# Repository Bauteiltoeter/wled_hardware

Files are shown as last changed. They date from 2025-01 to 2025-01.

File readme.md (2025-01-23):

# Universal WLED board with ethernet switch

This projects aims to deliver a hardware platform to drive smart LEDs like WS2812, SK6812 and similar.
It can operate from the LED strips supply voltage (5-24V) and provides a webinterface over WiFi or Ethernet.
The integrated ethernet switch enables an ethernet daisy chain.
Each LED output is individually fused to allow for thiner wires and high current powersupplies.
Some smart LEDs have trouble reading 3.3V data signals with a high supply voltage. This board contains a 5V output driver to avoide data corruption.

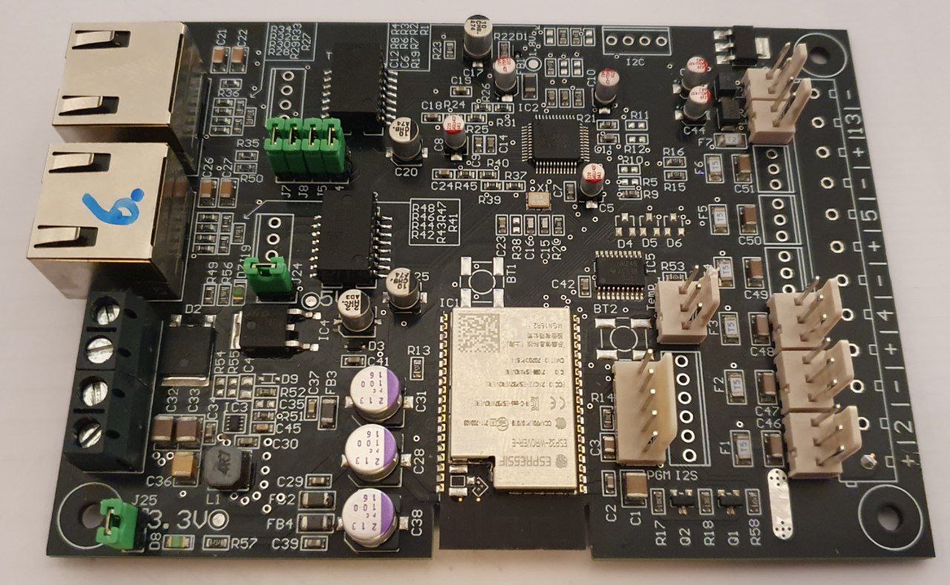
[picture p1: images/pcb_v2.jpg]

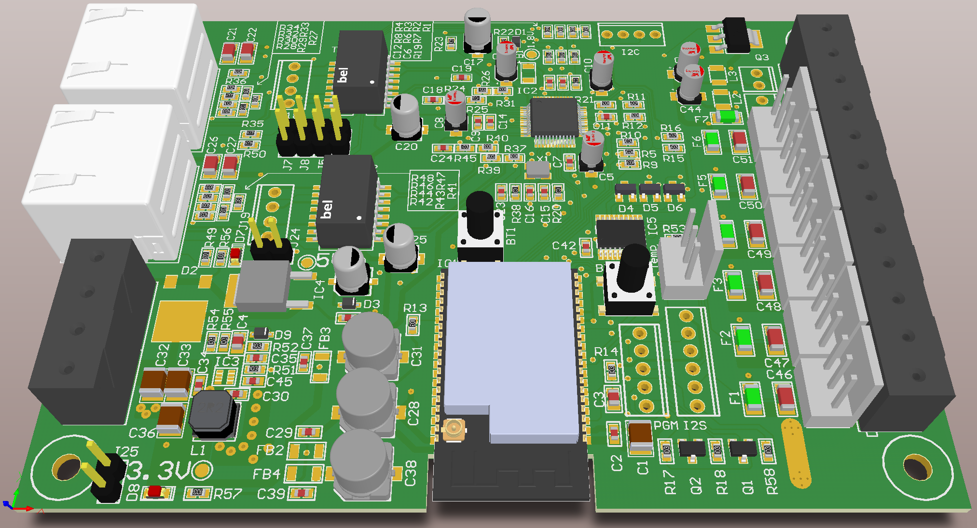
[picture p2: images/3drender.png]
3D Rendering of the board


## Features
* WLED compatible
* Input Voltage 5-24V
* Integrated Ethernet switch for daisy chaining
* 6 LED outputs with 5V signal level
* 5A per output, 16A total
* Every output fused individually
* Output using 2.54mm pins or AKZ500 screw terminals
* 2 fan connectors with PWM
* Connector for DS18B12 temperature sensors
* Connector for I2S microphones (shared with LED output 4/5)
* LEDs can be disabled with jumpers
* Reverse protection diode, will short-circuit the supply if reversed
* Board size 110 x 80mm

## Building it
PCB manufacturing data (gerber), schematic and (mostly) mouser BOM are available in directory "hardware/releases/". PCB was manufactured by JLCPCB including stencil, but hand soldering is an option (L1 needs hot air soldering).
Solder thick wires (1.5 - 2.5mm2) on the exposed traces on the bottom to allow high output currents.

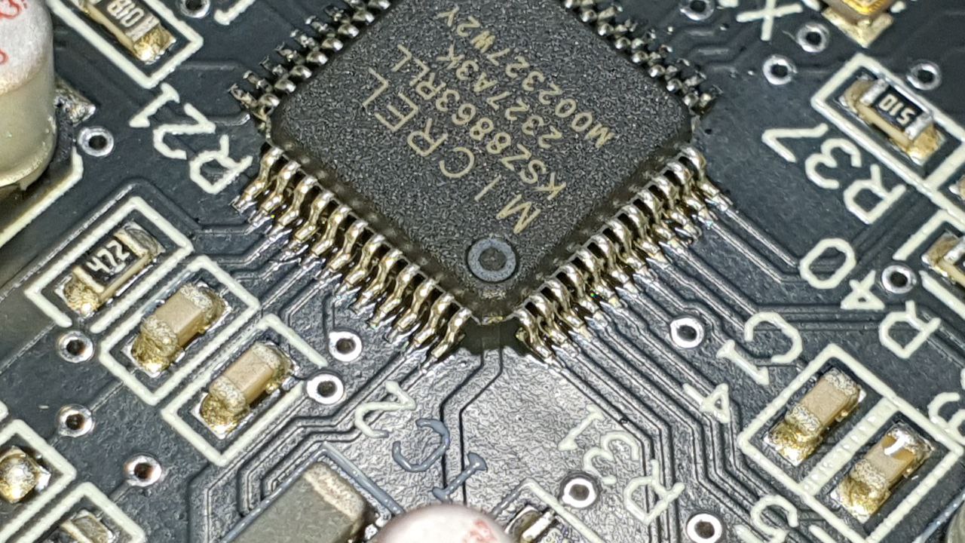
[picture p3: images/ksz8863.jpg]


## Cost
BOM costs are around 45€ + Board + Stencil

## License
This hardware is licensed under CERN open hardware license [CERN-OHL-W](license.txt)

## Software
Compatible with my fork of WLED, available [here](https://github.com/Bauteiltoeter/WLED2/tree/cyberlamp).

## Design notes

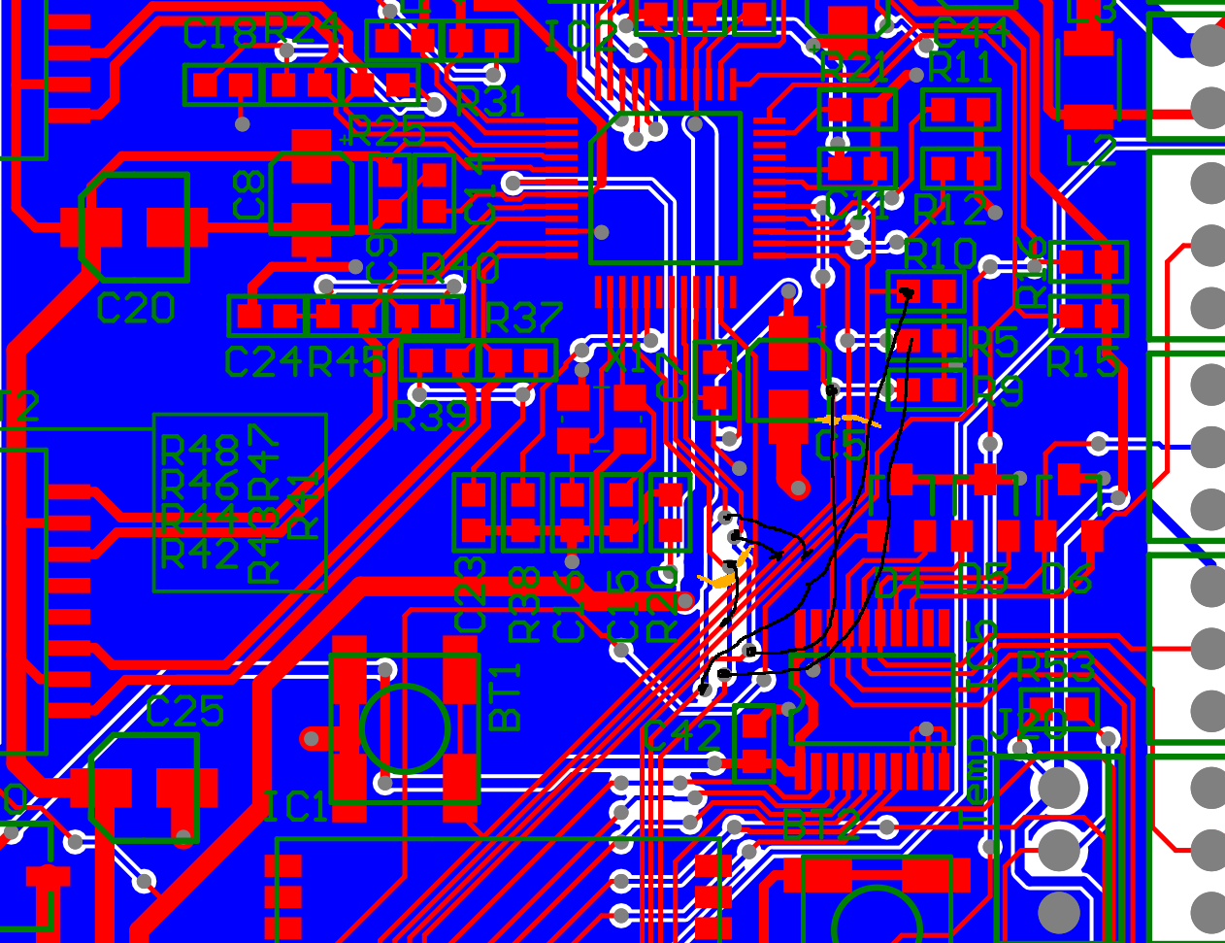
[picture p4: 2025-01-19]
hardware/cyberlamp/mod.png

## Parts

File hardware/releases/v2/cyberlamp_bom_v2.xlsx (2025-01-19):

Comment | Designator | Footprint | mouser code | Quantity | Price/piece | Sum
51R 100mW 0603 | R24, R25, R26, R28, R29, R30, R31, R32, R33, R34, R37, R39, R40, R42, R43, R44, R45, R46, R47, R48 | res0603 | 791-WR06X510JTR | 20 | 0.013 € | 0.260 €
100nF 50V MLCC 0603 | C2, C6, C7, C9, C11, C12, C14, C18, C19, C23, C24, C29, C30, C34, C37, C39, C41, C42 | 0603 | 80-C0603X104K3R | 18 | 0.034 € | 0.612 €
1k 100mW 0603 | R2, R3, R9, R21, R23 | res0603 |  | 5 | 0.034 € | 0.170 €
4k7 100mW 0603 | R8, R13, R15, R16, R19, R53, R56, R58 | res0603 | 603-RE0603FRE074K7L | 8 | 0.080 € | 0.640 €
5A/63V Fuse, 1206 | F1, F2, F3, F4, F5, F6, F7 | 1206 | 530-C1T5 | 7 | 0.211 € | 1.477 €
PSS 254/3G | J12, J13, J14, J15, J16, J17, J20 | PSS 3pol | Reichelt PSS 254/3G | 7 | 0.040 € | 0.280 €
10K 100mW 0603 | R14, R17, R18, R22, R52 | res0603 | 603-RE0603FRE0710KL | 5 | 0.008 € | 0.040 €
1µF 50V MLCC 1206 | C46, C47, C48, C49, C50, C51 | 1206 | 810-C3216X7R1H105K | 6 | 0.063 € | 0.378 €
Elko 22µF 6.3V WE | C5, C8, C10, C13, C43, C44 | WCAP-ASLU | 710-865090168010 | 6 | 0.271 € | 1.626 €
SL 1X2G 2,54 | J4, J5, J7, J8, J24, J25 | SL_1x2 2.54mm |  | 6 |  | 0.000 €
220R 100mW 0603 | R35, R36, R49, R50 | res0603 |  | 4 | 0.008 € | 0.032 €
HI1206N101R-10 | FB1, FB2, FB3, FB4 | 1206 | 875-HI1206N101R-10 | 4 | 0.132 € | 0.528 €
NP0 | C21, C22, C26, C27 | 1206 | 710-885342208024 | 4 | 0.094 € | 0.376 €
CDSOT23-SM712 | D4, D5, D6 | SOT23 | 652-CDSOT23-SM712 | 3 |  | 0.000 €
Elko_100uF_16V_PanasonicC | C28, C31, C38 | PANASONIC_C | 667-16SVPC100M | 3 | 0.499 € | 1.497 €
Elko_10uF_16V_PanasonicB | C17, C20, C25 | Panasonic_b | 667-EEE-HB1C100R | 3 | 0.126 € | 0.378 €
PSS 254/4G | J18, J19, J23 | PSS 4pol | Reichelt PSS 254/4G | 3 | 0.100 € | 0.300 €
18pF 50V MLCC 0603 | C15, C16 | 0603 | 603-CC0603JRNPABN180 | 2 | 0.046 € | 0.092 €
1N4148WS | D1, D3 | SOD323 | 512-1N4148WS | 2 | 0.106 € | 0.212 €
1µF 25V MLCC 0805 | C3 | 0805 | 187-CL21B105KAFNFNE | 1 | 0.028 € | 0.028 €
22uF 35V X5R 1210 | C32, C33 | 1210 | 963-GMK325BJ226MM-P | 2 | 0.476 € | 0.952 €
75R 100mW 0603 | R27, R41 | res0603 | 603-RC0603FR-7W75RL | 2 | 0.020 € | 0.040 €
AKZ500 | J9, J10 | AKZ500/2 | 845-34.102 | 2 | 0.646 € | 1.292 €
FMMT 617 | Q1, Q2 | SOT-23 | 522-FMMT617TA | 2 | 0.245 € | 0.490 €
Green LED, 0603 | D7, D8 | G0805 | 710-150080GS75000 | 2 | 0.174 € | 0.348 €
PSS 254/2G | J21, J22 | PSS 2pol | Reichelt PSS 254/2G | 2 | 0.050 € | 0.100 €
RJ45 | J3, J6 | MTJ-88ARX1-FSM-PG-LH | 737-MTJ88ARX1FSMPGLH | 2 | 0.761 € | 1.522 €
S558-5999-U7-F | T1, T2 | S558-5999-U7-F | 530-S558-5999-U7-F | 2 | 1.430 € | 2.860 €
TDL_NL322522 | L2, L3 | NL322522 | 810-NLV32T-220J-EF | 2 | 0.142 € | 0.284 €
TL3301 JLead | BT1, BT2 | TL3301_Jlead | 612-TL3301TF160QJ | 2 | 0.363 € | 0.726 €
10nF 50V MLCC 0603 | C45 | 0603 |  | 1 |  | 0.000 €
10uF 63V X7R 1210 | C1 | 1210 | 81-GRM32ER71J106MA2L | 1 | 0.537 € | 0.537 €
11k8 100mW 0603 | R20 | res0603 | 603-RT0603DRE0711K8L | 1 | 0.031 € | 0.031 €
2,2µF 50V Size B Elko | C40 | SIZE_B | 667-EEE-HC1H2R2R | 1 | 0.163 € | 0.163 €
25MHz | X1 | ABM8 | 815-ABM8-25-B2-T | 1 | 0.474 € | 0.474 €
2k7 100mW 0603 | R57 | res0603 | 603-RE0603FRE072K7L | 1 | 0.011 € | 0.011 €
30k9 100mW 0603 | R51 | res0603 | 652-CR0603-FX3092ELF | 1 | 0.012 € | 0.012 €
47pF MLCC 0603 | C35 | 0603 | 187-CL10C470JC81PNC | 1 | 0.014 € | 0.014 €
47uF 16V X7R 1210 | C36 | 1210 | GRM32ER61C476KE15L | 1 | 0.698 € | 0.698 €
74AHCT245 | IC5 | TSSOP20 | 595-SN74AHCT245PWRE4 | 1 | 0.626 € | 0.626 €
AKZ500 | J11 | AKZ500/12 | 845-34.112 | 1 | 2.130 € | 2.130 €
BUK98180 | Q3 | SOT223 | 771-BUK98180-100ACUX | 1 | 0.419 € | 0.419 €
BZT52-C4V3S_R1_00001 | D9 | SOD323 | 241-BZT52C4V3SR10000 | 1 | 0.075 € | 0.075 €
ESP32-WROVER-E | IC1 | ESP32-WROVER-I | 356-ESP32WRVREN16R2 | 1 | 3.450 € | 3.450 €
KSZ8863RLL | IC2 | LQFP48 | 998-KSZ8863RLL | 1 | 5.510 € | 5.510 €
L77805CDT-TR | IC4 | D-PAK | 511-L7805CDT-TR | 1 | 0.841 € | 0.841 €
PSS 254/5G | J1 | PSS 5pol | Reichelt PSS 254/5G | 1 | 0.070 € | 0.070 €
PSS 254/6G | J2 | PSS 6pol | Reichelt PSS 254/6G | 1 | 0.160 € | 0.160 €
SRN5040-4R7M | L1 | BOURNS SRN5040 | 652-SRN5040-4R7M | 1 | 0.278 € | 0.278 €
TPS62933F | IC3 | SOT583-8 | 595-TPS62933FDRLR | 1 | 0.939 € | 0.939 €
V20PWM12H | D2 | TO-252AE | 78-V20PWM12HM3/I | 1 | 0.739 € | 0.739 €
DNP | R1, R4, R5,R6,R7, R10,R11,R12, R38, R54, R55, C4
 |  |  |  |  | Sum: | 34.72 €
 |  |  |  |  | Tax: | 6.60 €
 |  |  |  |  | Total: | 41.31 €

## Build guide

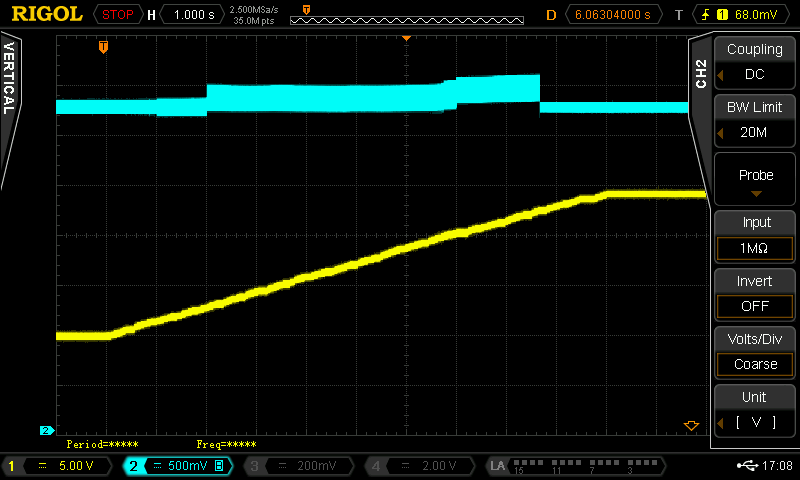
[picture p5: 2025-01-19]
measurements/DS4_QuickPrint5.png

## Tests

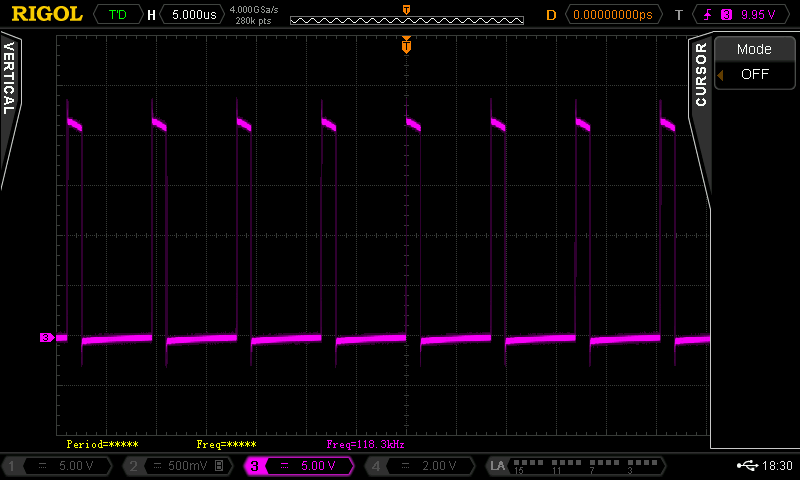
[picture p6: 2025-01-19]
measurements/dc_switch_200mA_21V.png

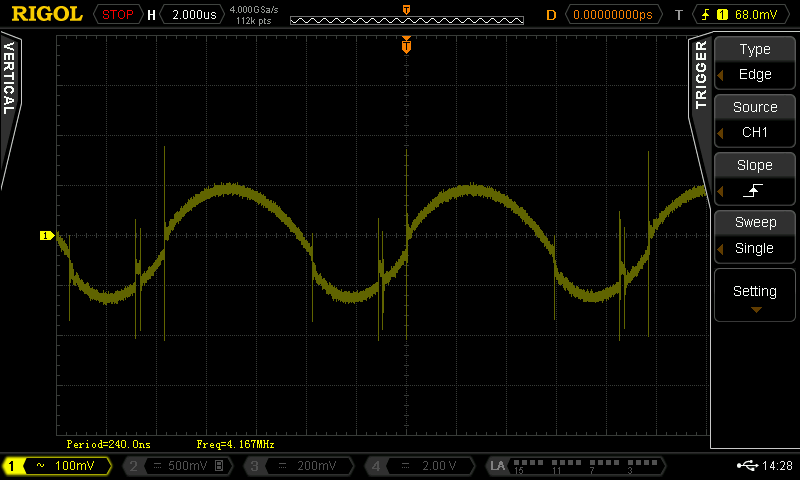
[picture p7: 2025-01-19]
measurements/output_2.png

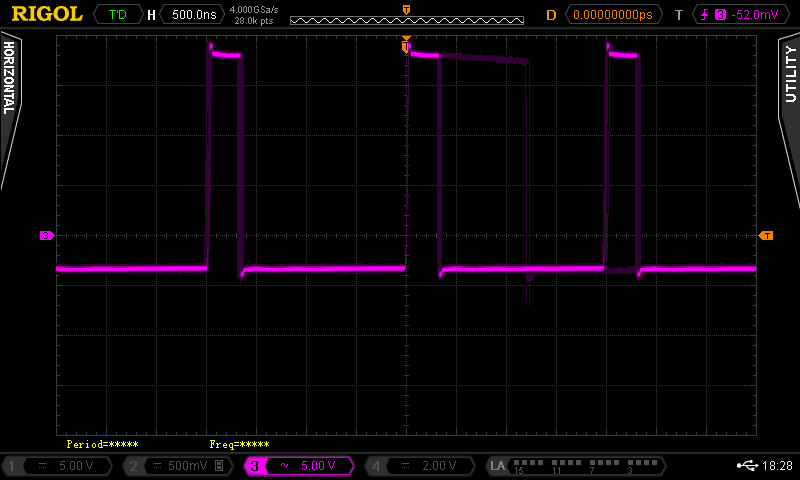
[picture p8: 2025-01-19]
measurements/ac_switch_200mA_21V.png

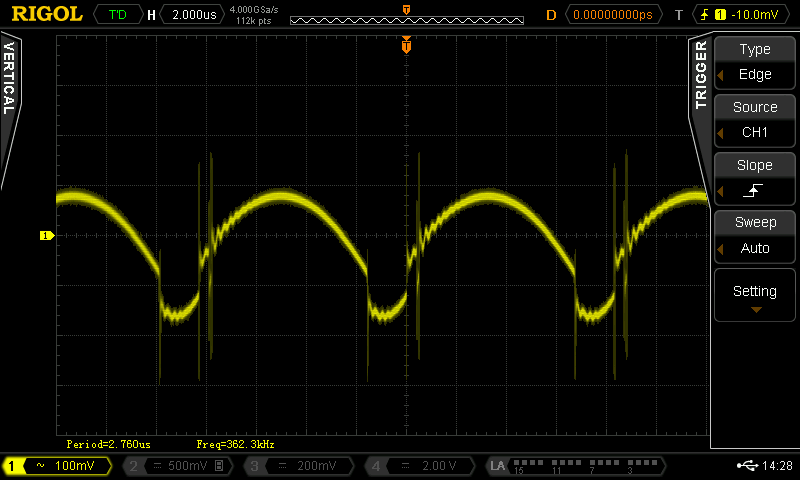
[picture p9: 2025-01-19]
measurements/output_1.png

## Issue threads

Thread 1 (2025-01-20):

Kontaktaufnahme

relaxibus, 2025-01-20:
Hallo Torben,
ich würde gerne mit dir bezüglich dein ESP32 und ETH Switch Projekt in Kontakt treten. Ich habe ein ähnliches Board Projekt und würde mich gerne austauschen.

Beste Grüsse, J

Bauteiltoeter, 2025-01-20:
Hallo J,

okay, gerne. Hast du eine Email-Adresse wo ich dich erreichen kann?

relaxibus, 2025-01-21:
Hallo,

relaxibus@gmail.com

Freue mich auf einen Austausch.

Closed 2025-01-22.

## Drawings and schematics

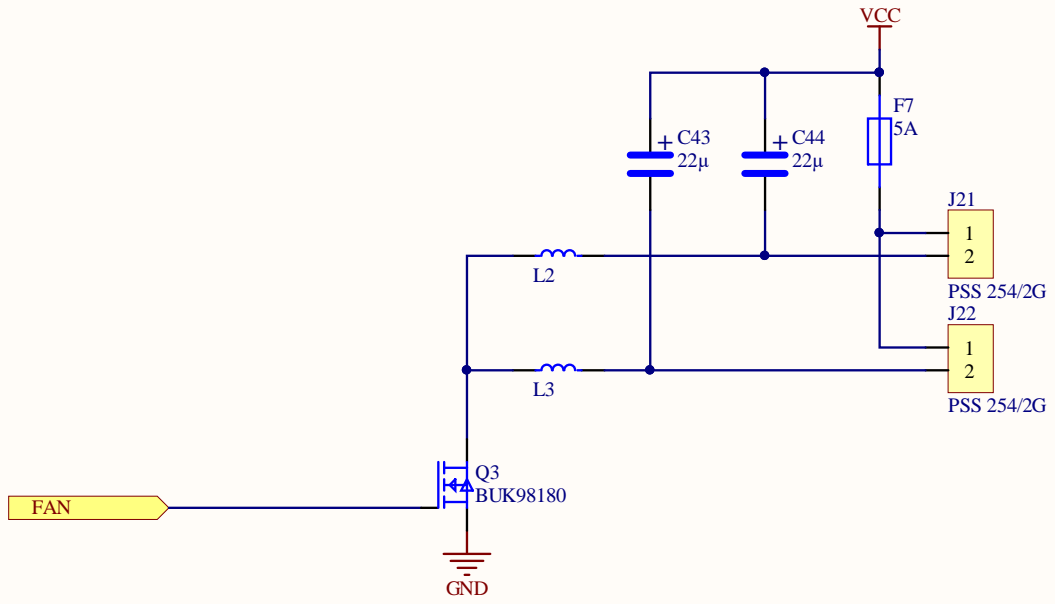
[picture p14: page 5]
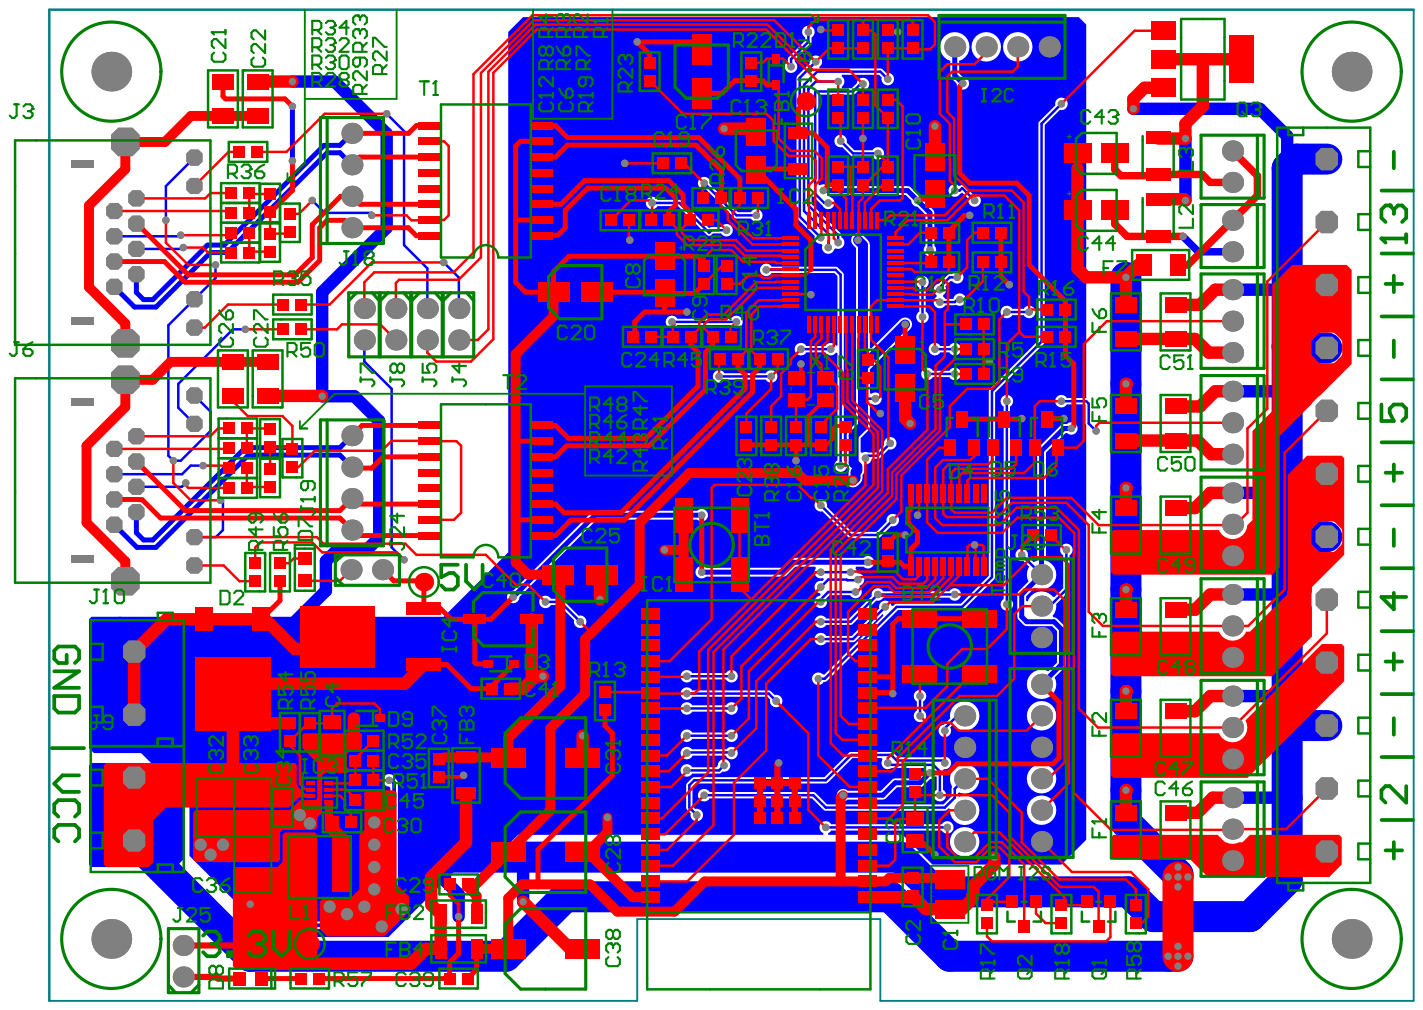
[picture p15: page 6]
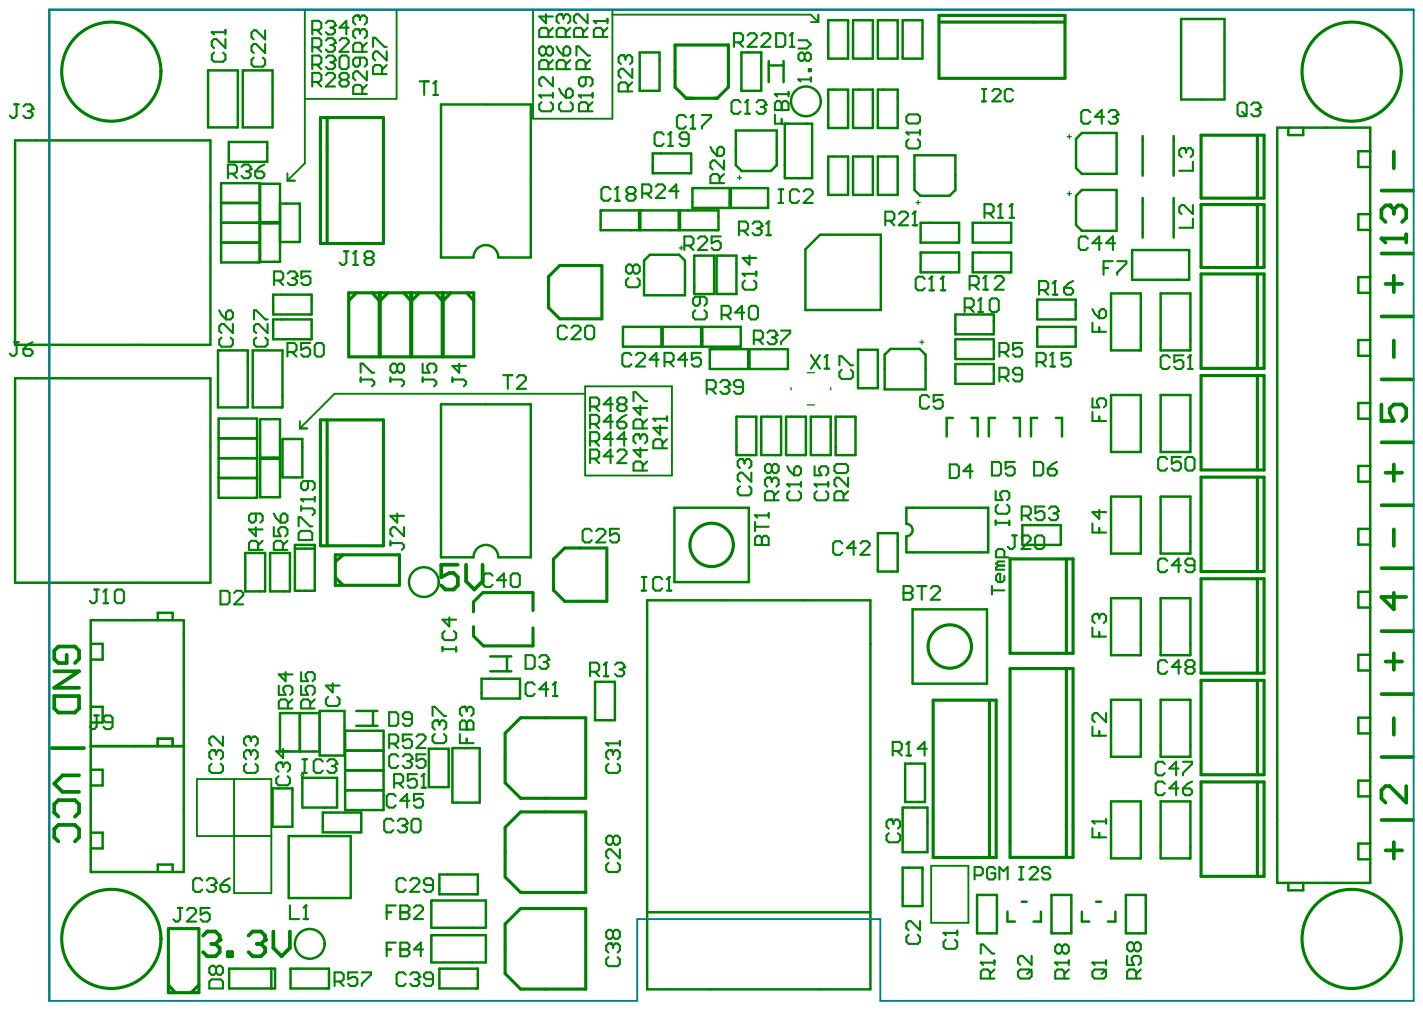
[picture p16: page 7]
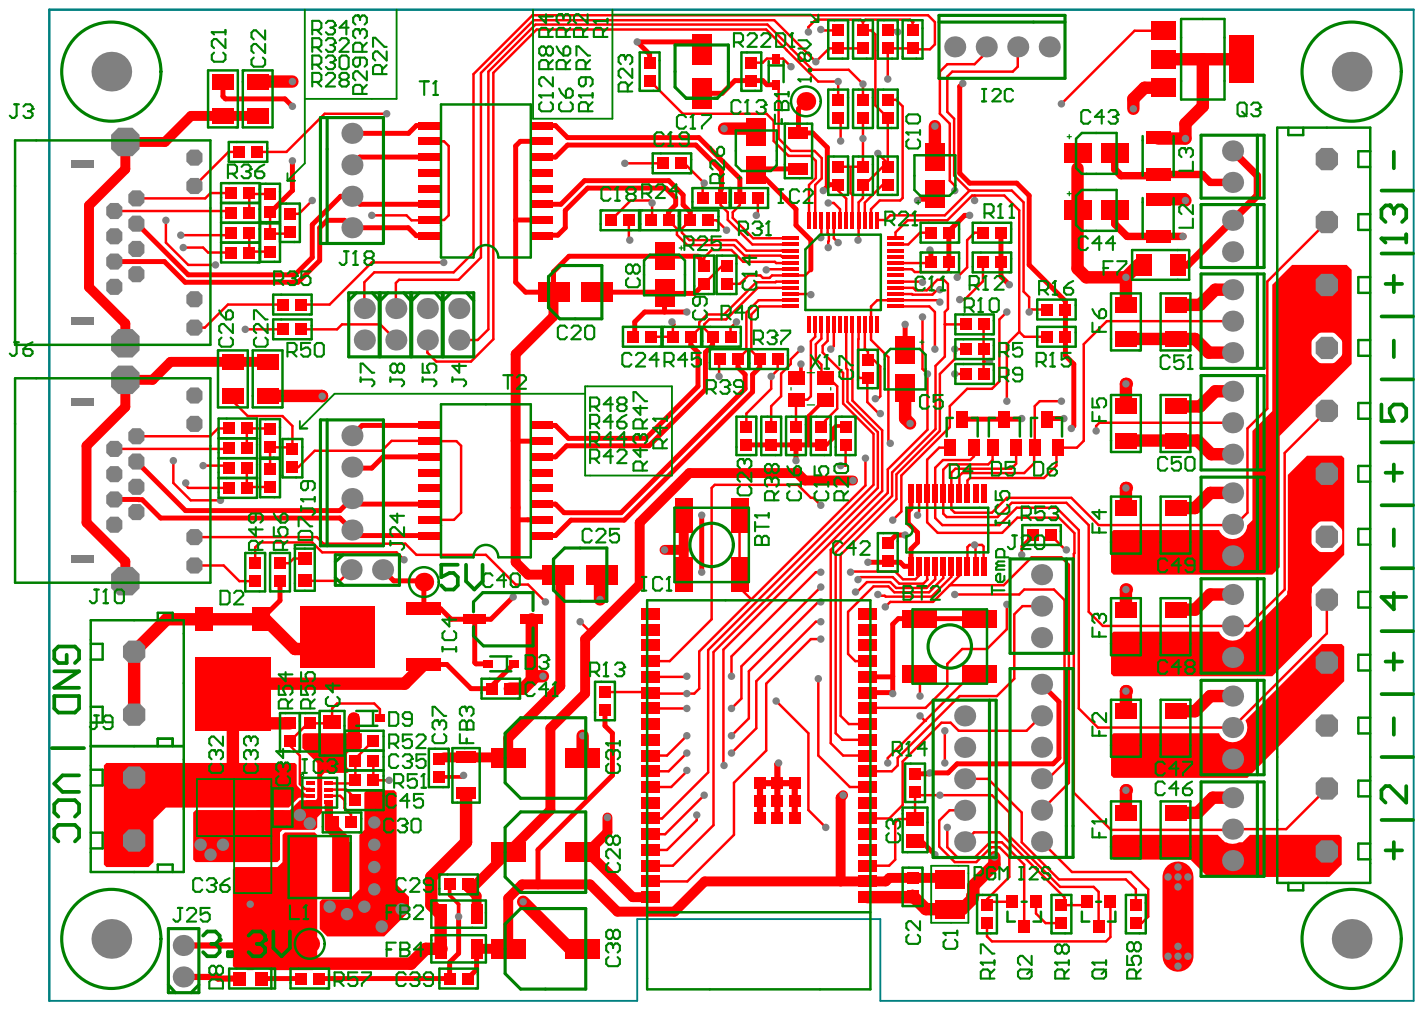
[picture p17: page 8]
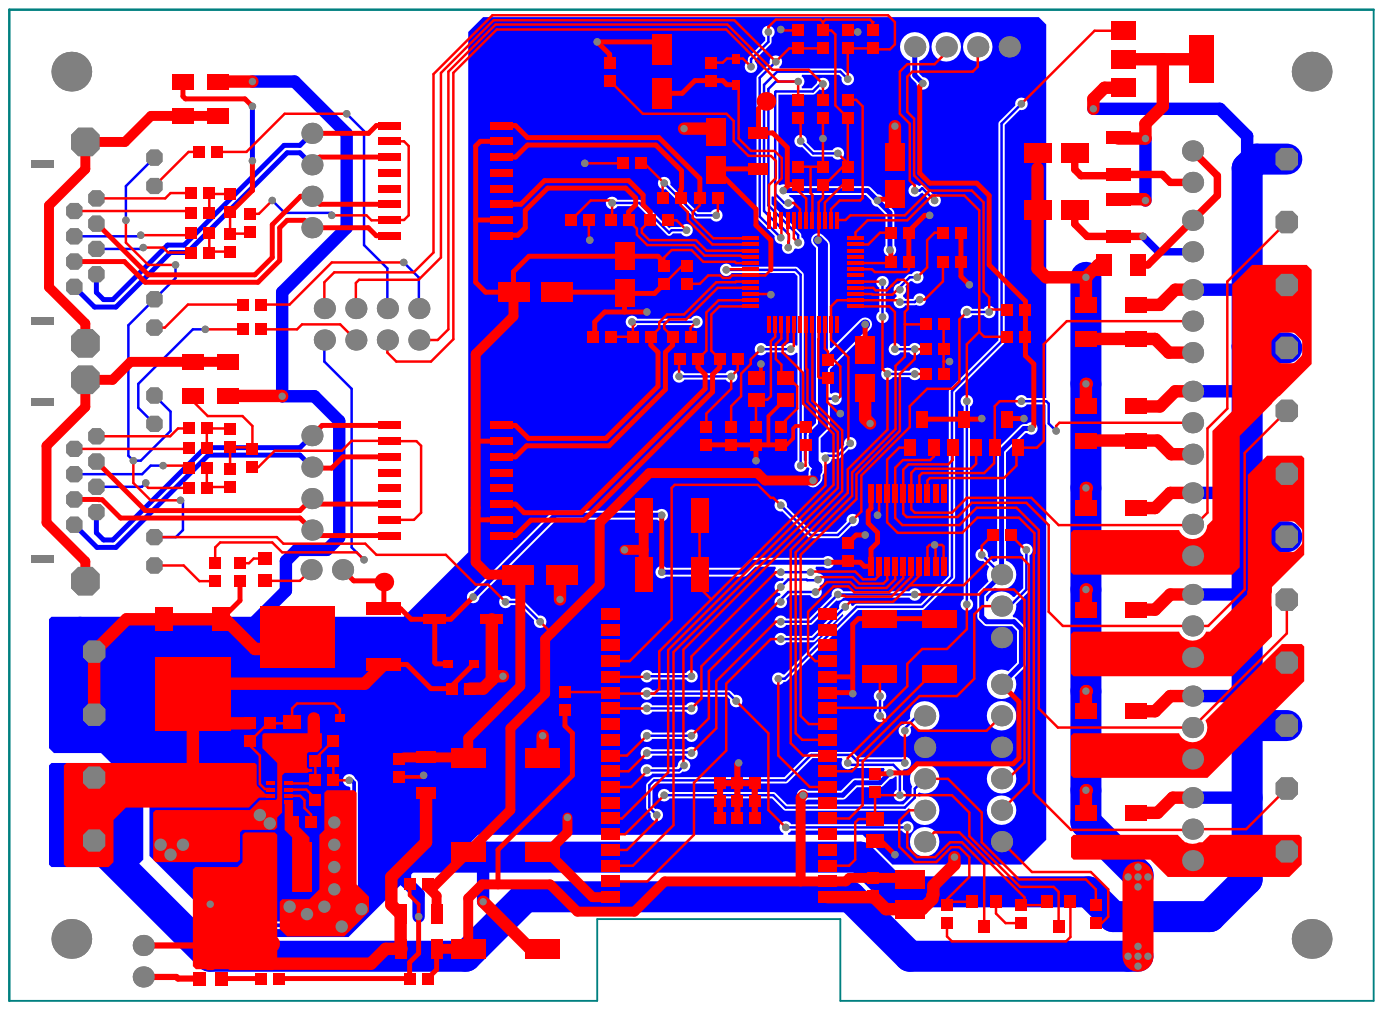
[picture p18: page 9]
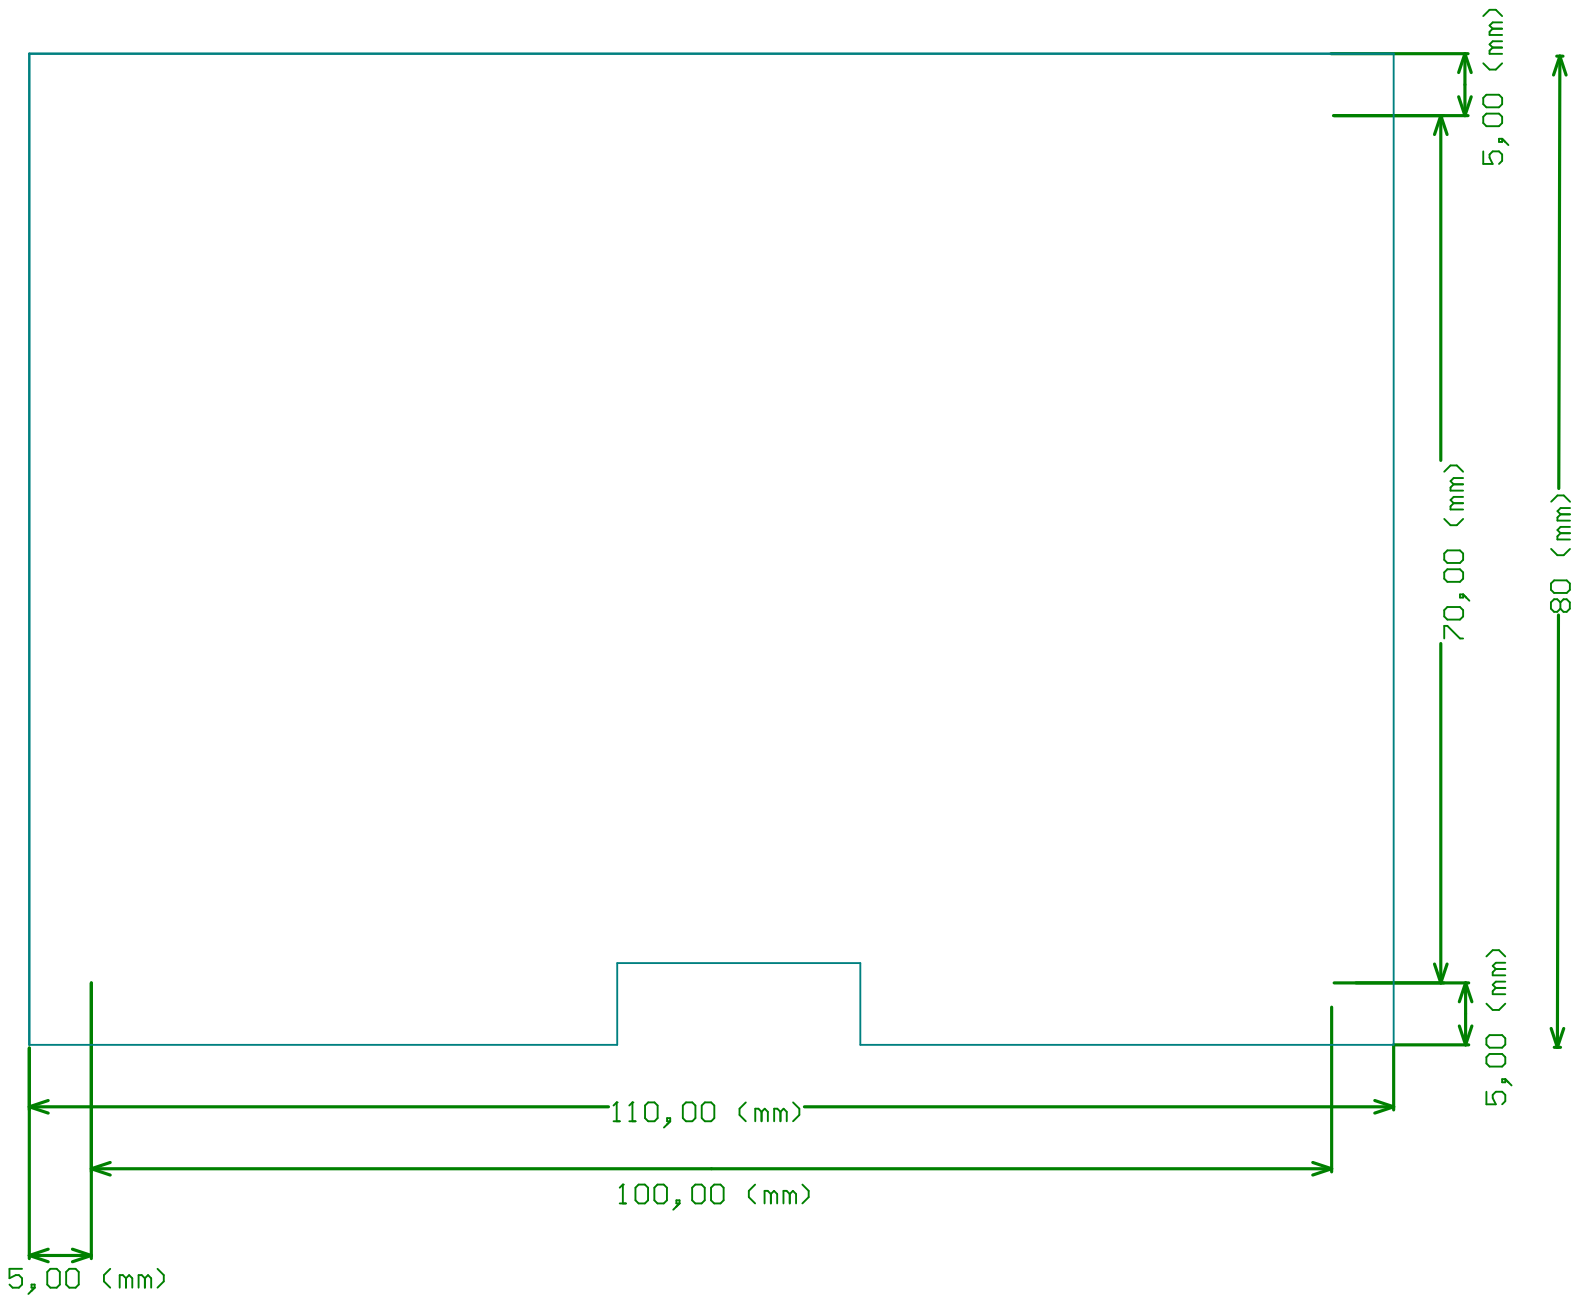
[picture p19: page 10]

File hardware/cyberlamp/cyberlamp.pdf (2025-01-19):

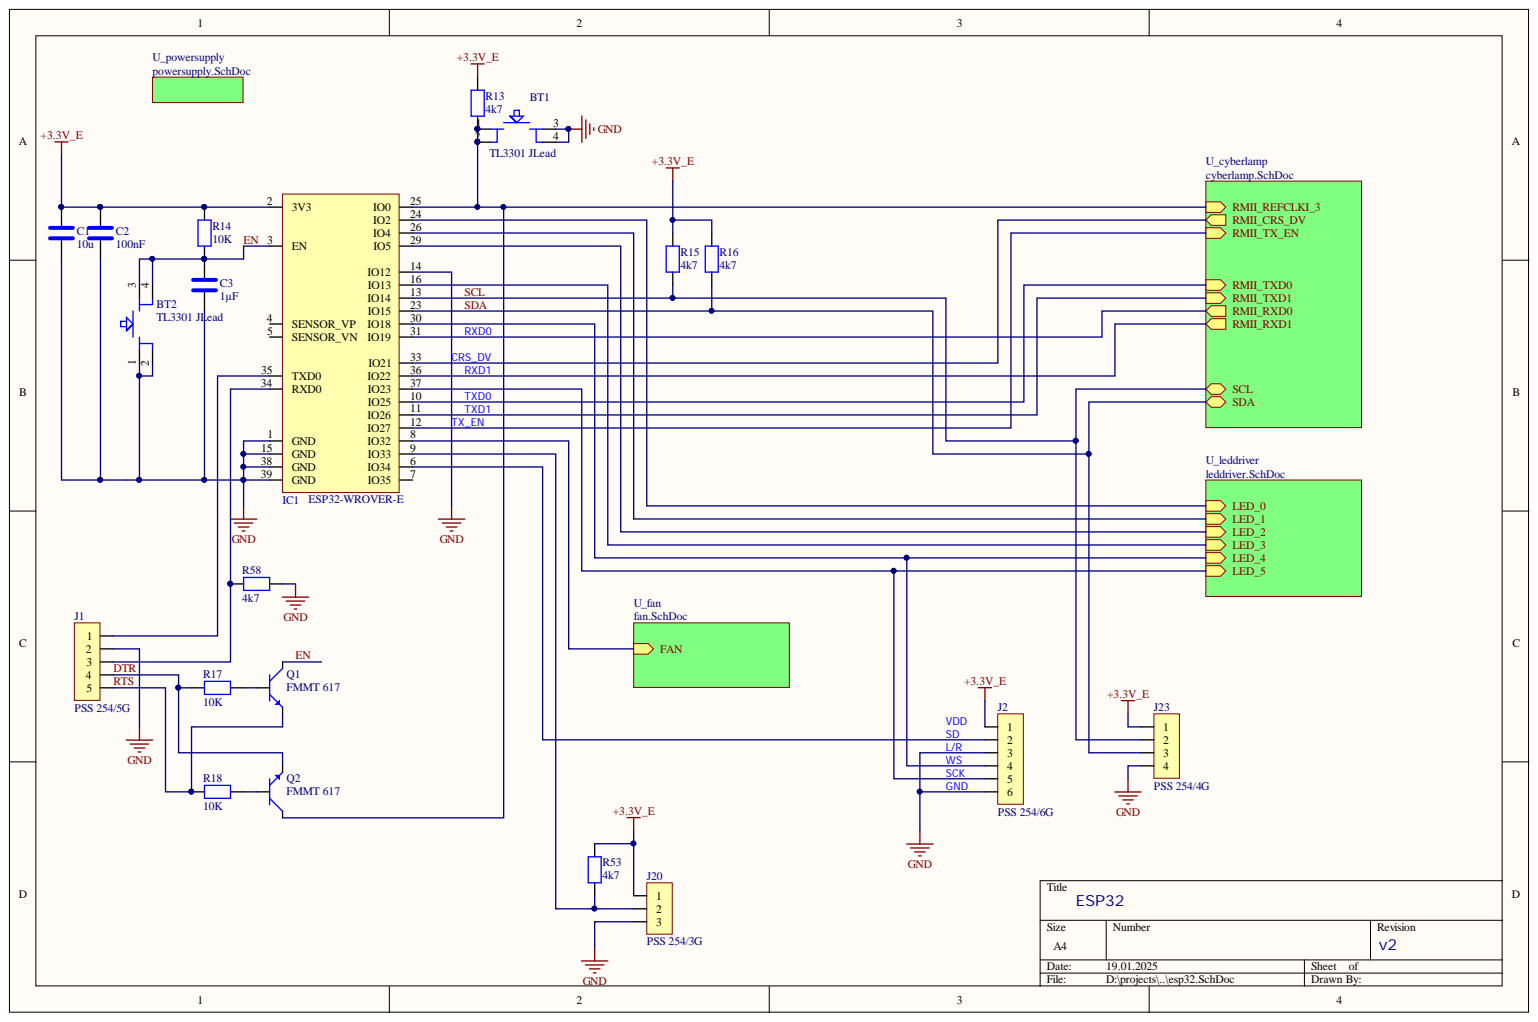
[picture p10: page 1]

IO2 IO4 EN IO5 IO1 2 IO1 3 IO1 4 IO1 5 SENSOR_VP IO1 8 SENSOR_VN IO1 9 IO2 1 TXD0 IO2 2 RXD0 IO2 3 IO2 5 IO2 6 IO2 7 GND IO3 2 GND IO3 3 GND IO3 4 GND IO3 5 | 2 4

2 6
2 9

1 4
1 6
1 3 | S C L
2 3 | SDA

3 | 4 | 3 7
1 | 1 0

1 1
1 2

SDL/R WS

SCK

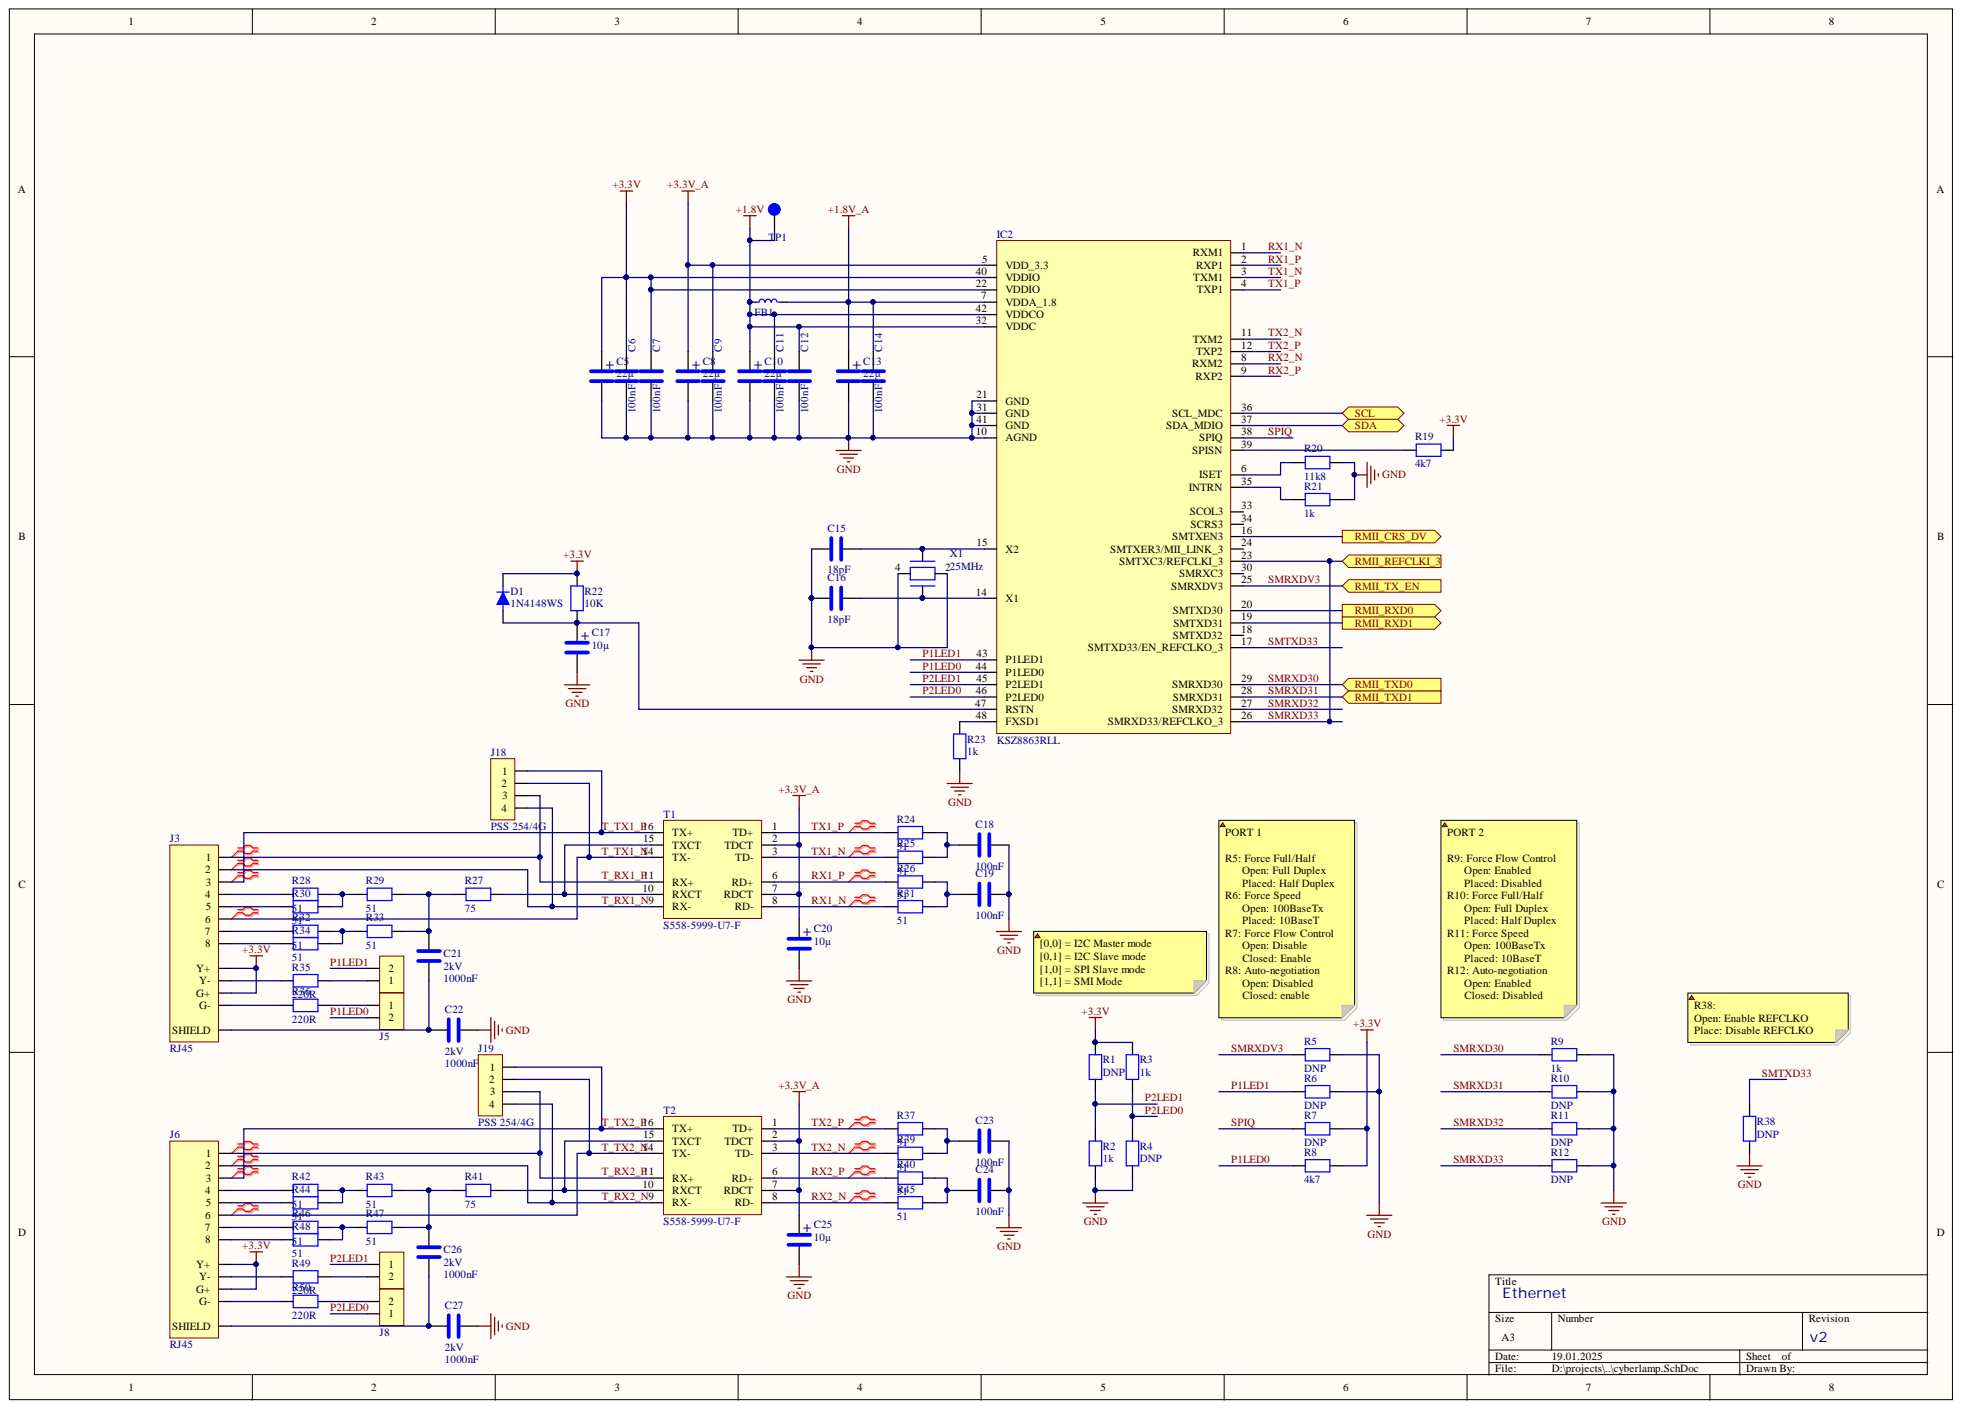
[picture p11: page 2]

4 0
7 2

1 | 0 | 3 8 S P I Q

5 1 | R4 7
5 R4 1 6

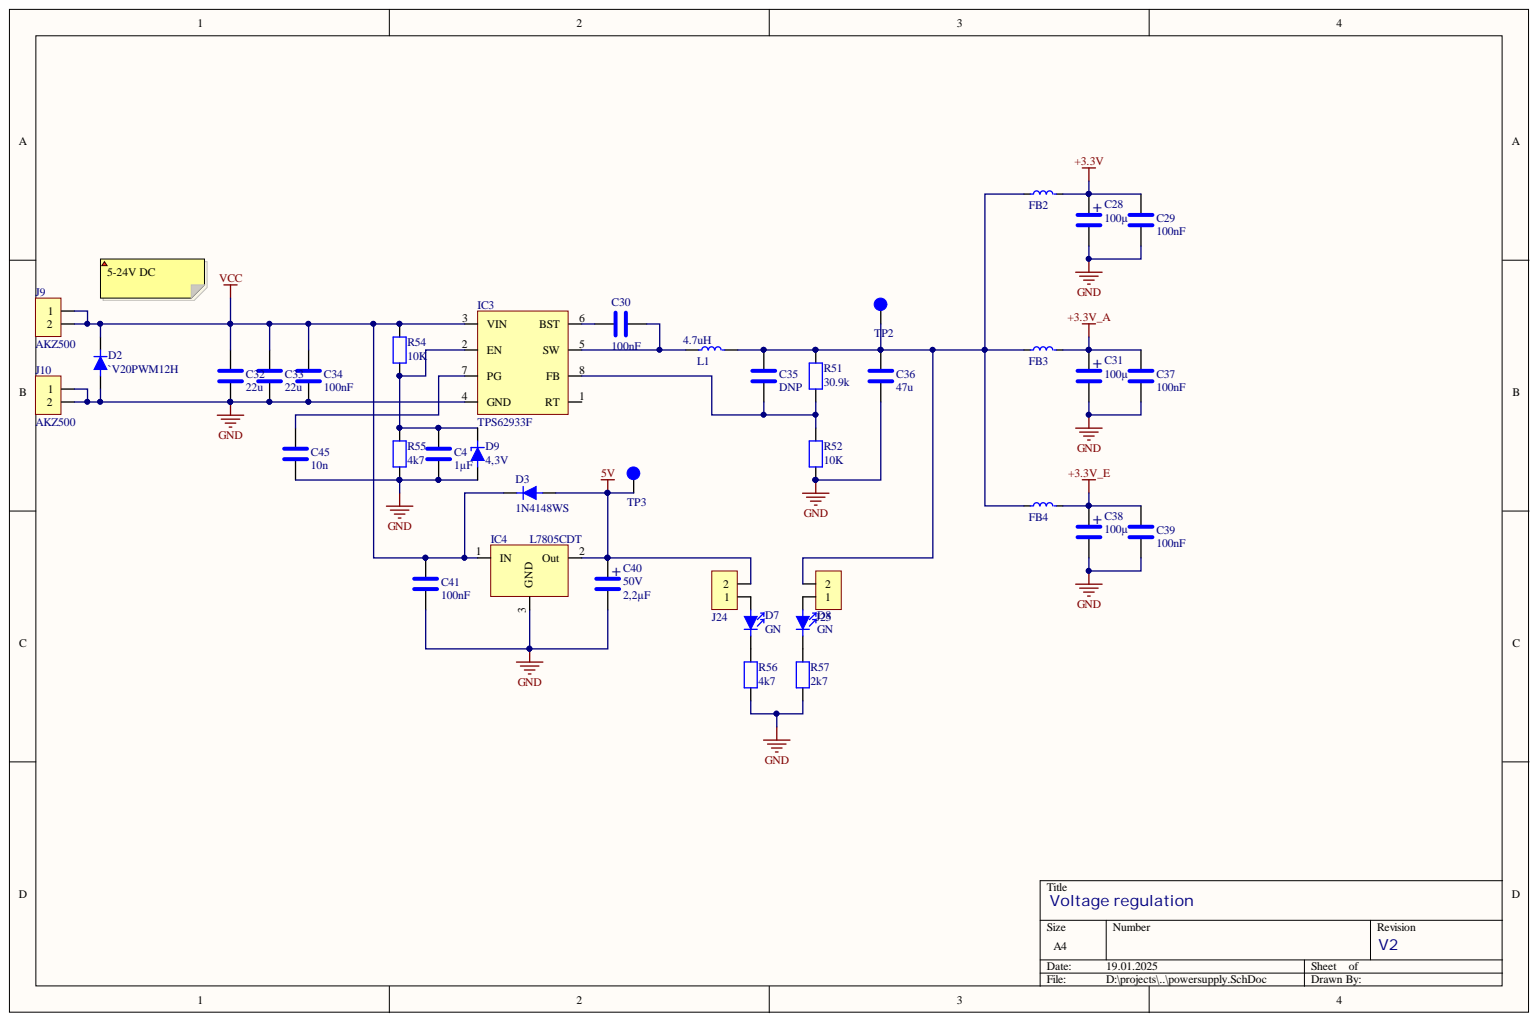
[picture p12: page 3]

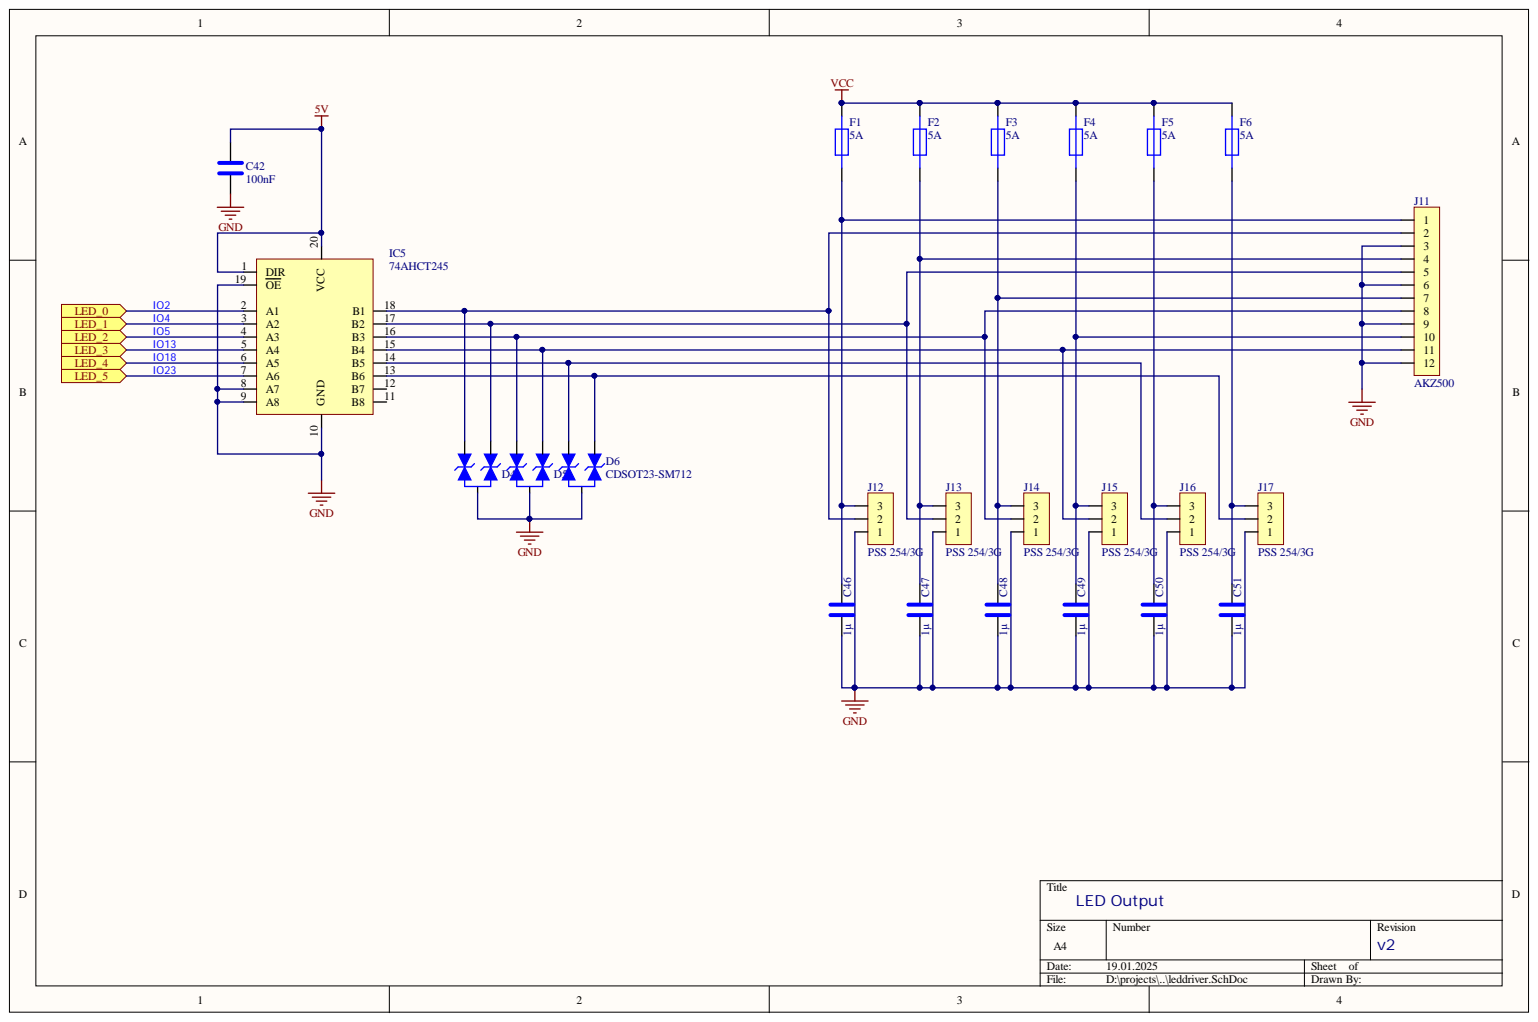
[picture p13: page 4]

1 7
1 6
1 5
1 4

1 2 1 | | D6 CDSOT2 3-S M 7 1 2
